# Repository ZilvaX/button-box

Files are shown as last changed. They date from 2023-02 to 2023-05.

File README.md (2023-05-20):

# Button Box

The `release/` directory holds an easier to print version of the designs. The
designs in the main directory have the layers stacked, to help with alignment of
the layers during the design process.

## Bubu Box

Stickless fightstick/button box acrylic case design. Intended to be cut from 3mm
, 6mm acrylic and put together using acrylic glue/cement.

The design dimensions are for a 39mm tall box, but upon building, the interior
dimensions of the box were a bit low, resulting in the need to bend the Sanwa
button pins and the Raspberry Pi Pico connectors being too visible through the
top layer. Should experiment with more room in the interior of the box.

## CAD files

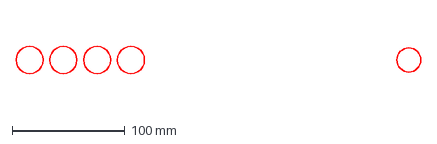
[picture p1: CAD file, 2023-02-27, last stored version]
release/Personal - Buttonbox - Top Panel V0.2.dxf
359.4 x 25.1 mm

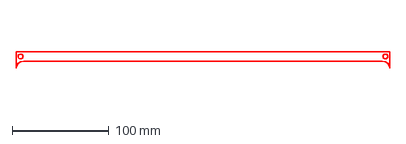
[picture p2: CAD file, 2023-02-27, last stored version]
release/Personal - Buttonbox - 30mm Top V0.2.dxf
386.0 x 17.3 mm

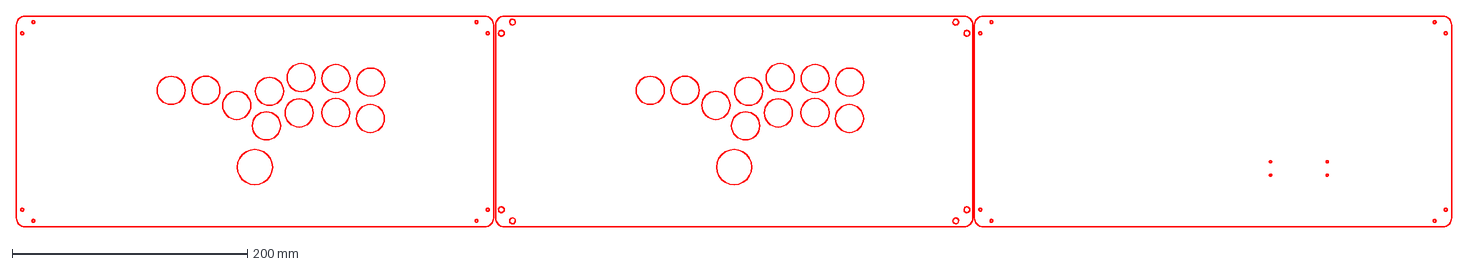
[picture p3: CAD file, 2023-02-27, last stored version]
release/Personal - Buttonbox - 3mm V0.2.dxf
1221.1 x 179.0 mm

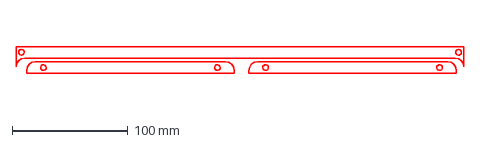
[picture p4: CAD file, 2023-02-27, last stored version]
release/Personal - Buttonbox - 30mm V0.2.dxf
386.0 x 23.1 mm

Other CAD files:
3D.blend
release/Full Model.blend
release/Top Panel 2.blend

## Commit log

2022-12-08 Add initial designs for fightstick
    Calibrating the finger joints to the kerf of the laser cutter.
    Kerf roughly 0.18mm ~ 0.2mm
2022-12-08 Set all stroke widths to .1mm
2022-12-08 Add test cutout with kerf adjustment
    Adjusted for a kerf of 0.18mm
2022-12-11 Update screw holes to 3mm
2022-12-12 Add kerf adjusted for .18mm layer
2022-12-12 Update stroke width to .1mm
2023-01-04 Update Top Inner Panel with new Sanwa cutouts
    Used 30mm for 24mm button cutouts
    Used 36mm for 30mm button cutout
    Support for screw-in
2023-01-05 Update Top Inner Layer to use standard cutouts
    This should still support screw-in buttons. Need to verify whether
    snap-ins work alright
2023-01-05 Add rough Blender model of design
    [3D.blend]
2023-01-06 Update corner rounding to 7.5mm
    [3D.blend]
2023-01-06 Centre the action button cutouts
2023-01-06 Add first standoff hole for top layer
2023-01-06 Add remaining standoff holes
2023-01-31 Update wall thickness to 10mm
2023-02-05 Add screw holes for middle layer left panel
2023-02-05 Finish middle layer
    Note still need to make the holes for the back panel
2023-02-05 Add top inner panel standoff holes
    Also reposition top inner panel to be in the same position as the other
    layers
2023-02-05 Fix top inner pannel missing standoff holes in group
2023-02-05 Align buttons on back panel
2023-02-07 Add standoff holes
    Note the holes need to be tested
2023-02-20 Move RP2040 standoff positioning
2023-02-26 Ready release files for printing/cutting
    [3D.blend, Full Model.blend, Top Panel 2.blend]
2023-02-26 Rename release files from 35mm to 30mm
2023-02-27 Add dxf formats for the vectors
    [Personal - Buttonbox - 30mm Top V0.2.dxf, Personal - Buttonbox - 30mm V0.2.dxf, Personal - Buttonbox - 3mm V0.2.dxf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]
2023-03-19 Replace top panel with two pieces
    Two pieces inteded to be glued to the back panel holding the back panel
    buttons
2023-03-19 Create top panel for glueing to top corners
2023-03-24 Unrelease V0.2
    [Full Model.blend, Personal - Buttonbox - 30mm Top V0.2.dxf, Personal - Buttonbox - 30mm V0.2.dxf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]
2023-04-16 Update RP2040 standoff
    Original cutout was too wide
2023-04-16 Replace standoff holes with hexes
    For a more stable standoff
    Note also the standoff holes were too small for the hex standoffs
2023-04-25 Add new middle layer with corners
    Intend for walls to be glued to the corners to form the middle layer
2023-04-26 Update corner pieces to support 6mm thick acrylic
2023-05-20 Increase standoff hex size for laser cutting
    Also increase the USB passthrough connector size
